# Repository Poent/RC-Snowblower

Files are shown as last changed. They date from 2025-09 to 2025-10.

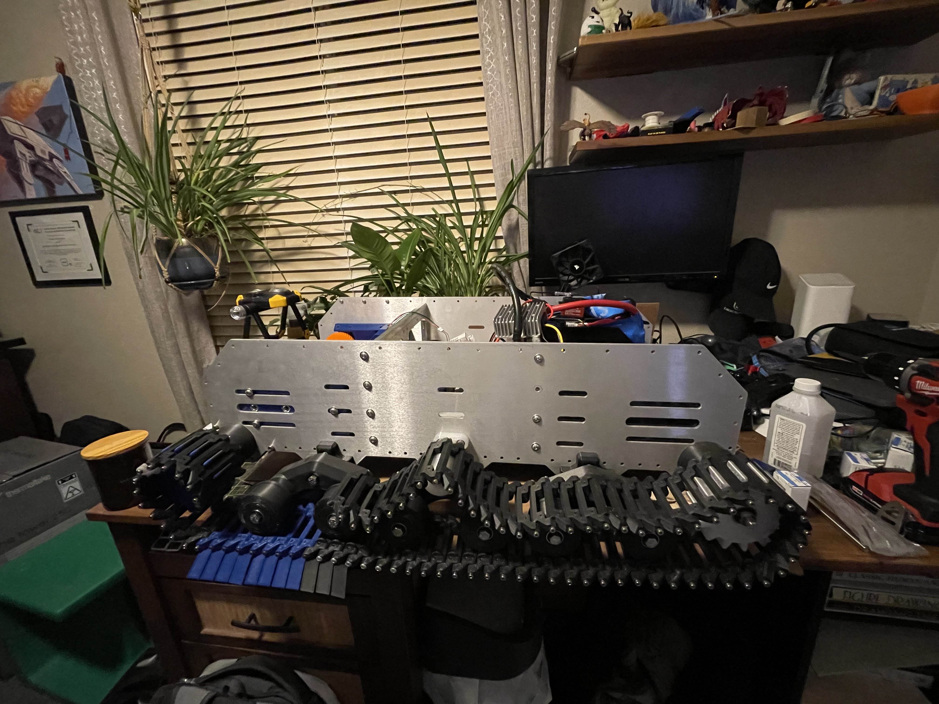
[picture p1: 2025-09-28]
Images/Sep 2025 Progress.jpg

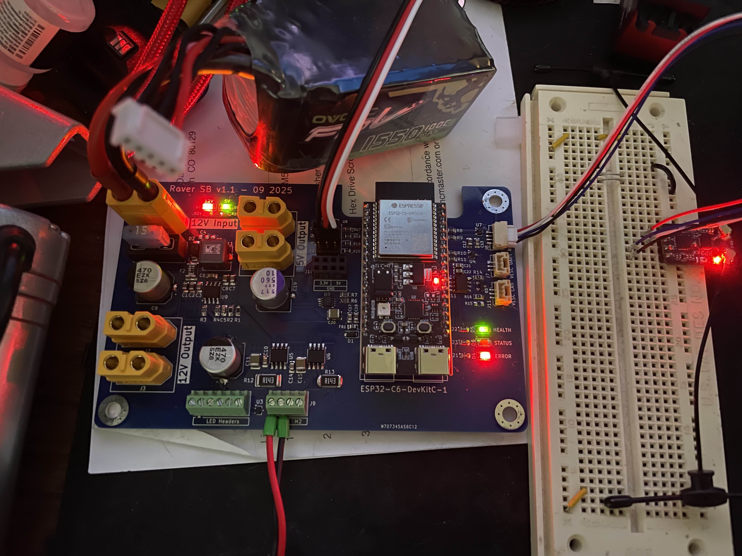
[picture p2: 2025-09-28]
Images/PCB-First-Boot.jpg

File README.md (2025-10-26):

# RC Snowblower Project

2025-09-27_19h33_31

====
LATEST UPDATES (10-26-2025):

2025-10-26_12h57_35

Working on designing the impeller and auger portion of the snowblower. Switched from using a worm gear assembly to a custom ring and pinion setup using a spiral bevel gear. Motor is a 190KV motor being driven at 38v nominal. Motor at full power (which we'll never do) will spin at about 7,200 RPM. the motor goes through a 3:1 reduction to the impeller. Impeller will spin at <2400 RPM. The impeller drives the input shaft of the auger gearbox, which has a 9:1 reduction. At full power that will result in the auger at about 250rpm. All of these are design maximums. The motor will likely be RPM limited to 60% total power in the VESC, more than halving all these totals. 

Hello everyone! Welcome to my crazy project.

Before diving into the details, here’s quick background on me and why I’m building this. Feel free to skip down to the status if you want the meat.

=====

### Who I am
I’m a tech leader in the OT/MSP space with ~15 years in IT services. I own our MSP tool stack, cybersecurity program, and AI/automation initiatives. I’m CISSP-certified and studied electrical engineering, game development/design, and aviation management in college. I have a wonderful wife and two kids, and my hobbies include art, design, programming, 3D printing, woodworking, and more.

### How this project started
About two years ago my wife sent me a video of the Yarbo snowblower. It’s a tracked outdoor platform with attachments for mowing, snowblowing, hauling, etc., and it can go fully autonomous with an RTK/GNSS setup. I loved it… until I saw it was about $5,000, which I can’t justify for a <15-foot driveway.

Then she sent a smiliar (but different) 3D-printed snowblower video. Once again I was hyped to look at building it, but the "basic" kit alone was about $4,000. My dreams were dashed again—but the seed was planted.... I’ve got experience with CAD, 3D printing, and electronics, so I decided to try building my own!

That’s this project. While my BOM is under $4k... it is far more expensive than I initially anticipated and I have a far higher respect for those alternatives. 

### What to expect here
I can't honestly recommend anyone replicate this build. Better platforms exist, and I'm not an engineer! While I intend to make everything functional, resilient, and high quality... there WILL be problems. If you choose to follow along or, god forbid, try to build one of these yourself.... PLEASE understand what you're getting into. It WILL be a significant investment and there is NO garuntee of a working platform at the end of it. Please don't anticipate assistance of any kind if you choose to build this. BUT.... if you do... please tell me! I would love to see what other people do. I intend to make and keep this project fully open source, and I have no dreams of making this into a commercial product at any point in time. 

For those of you that want to just check it out and/or follow along - then sit back, and enjoy the ride!

## Status

**Completed**
- Chassis assembled with CNC aluminum frame and 3D-printed interconnects
- Power system using Headway 40152 LiFePO₄ cells and JK BMS
- V1 controller board designed, produced, soldered, and tested
- Basic ESP32 firmware with CRSF input and VESC CAN telemetry
- Initial drivetrain movement tests

**In Progress**
- Finalizing V1 firmware for the ESP32 and carrier board
- Universal mount for the snowblower attachment
- Track stress testing and refinement
- Chassis cover design and integration (sealed against snow)

**Planned**
- Blower attachment design and integration
- Public-ready docs for CAD, electronics, and firmware
- BOM refinement for cost and reliability

# LATEST IMAGES
2025-09-27_19h33_31


Sep 2025 Progress 02
Sep 2025 Progress

2025-09-27_19h49_34
2025-09-27_19h50_09
2025-09-27_19h51_03

PCB-blanks

PCB-First-Boot

# Progress

**Completed:**
- Chassis structure assembled with CNC aluminum frame and 3D-printed interconnects  
- Power system finalized around Headway LiFePO₄ cells and JK BMS (150A).
- Custom V1 of controller board - Designed, produced, soldered, and tested.
- Basic firmware running on ESP32 with input decoding and VESC telemetry working. 
- Initial testing of drivetrain and basic movement functions

**In Progress:**
- Finalize V1 Firmware for ESP32 and carrier board
- Design and implement universal mount for snowblower attachment. 
- Track stress testing and refinement
- Chassis cover design and integration (sealed against snow ingress) - NOT STARTED

**Future work:**
- Design blower attachment and integration.
- Preparing the project for public release (this repository) and planning documentation for CAD, electronics, and firmware.
- Refine parts list and BOM to reduce cost, complexity, and improve reliability.

## Overview
This repository will contain (wish list) the complete design and implementation files for a remote-controlled snowblower, including:

- **CAD Models**: 3D designs and mechanical components
- **Electronics**: Circuit designs, PCB layouts, and component specifications
- **Code**: Control software and firmware
- **Documentation**: Build guides, specifications, and user manuals
- **Images**: Photos, diagrams, and visual documentation
- **Build Log**: Chronological record of design iterations, testing, and modifications

## Repository Structure

```
├── CAD/           # 3D models, drawings, and mechanical designs
├── Code/          # Control software and firmware
├── Docs/          # Documentation and guides
├── Electronics/   # Circuit designs and electrical components
├── Images/        # Photos, diagrams, and visual documentation
└── Build_Log/    # Chronological record of design iterations and testing

```

## Features (Planned)
- [done] Remote control operation
- [done] Variable speed control
- [done] High-performance BLDC motors with custom gearboxes
- [ ] Weather-resistant design
- [ ] Modular component system
- [ ] Universal Mount for attachments (snowblower, plow, etc.)

### Wish List
- Autonomous navigation capabilities
- Real-time telemetry
- Produce fully open-source hardware and software
- Develop 3D printed versions of key components to reduce cost

## Hardware Requirements
*To be documented*

## Software Requirements
*To be documented*

## Getting Started
*Build instructions coming soon*

## Contributing
*Contribution guidelines to be added*

## License
*License information to be added*

## Contact
*Contact information to be added*

---
*This README will be updated as the project progresses.*

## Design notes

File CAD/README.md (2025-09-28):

# CAD Files
This directory will contain all CAD files related to the RC Snowblower project. Placeholder for now...

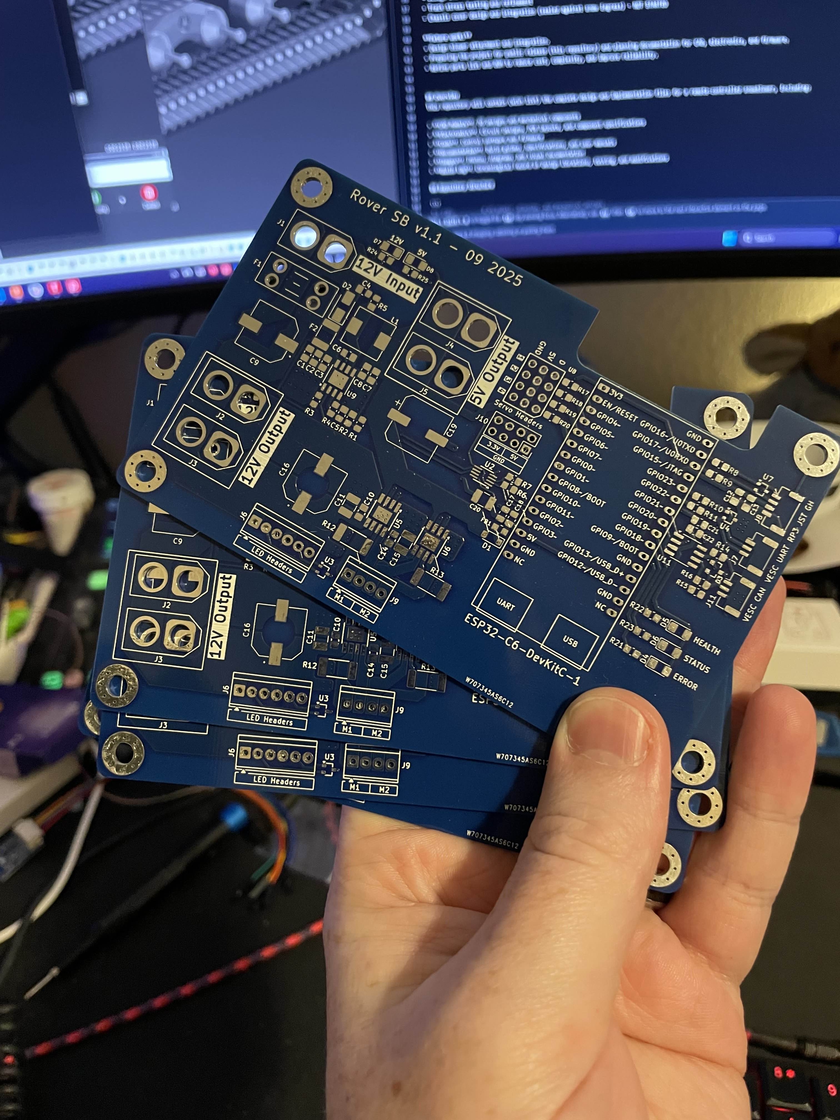
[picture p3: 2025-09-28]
Images/PCB-blanks.jpg

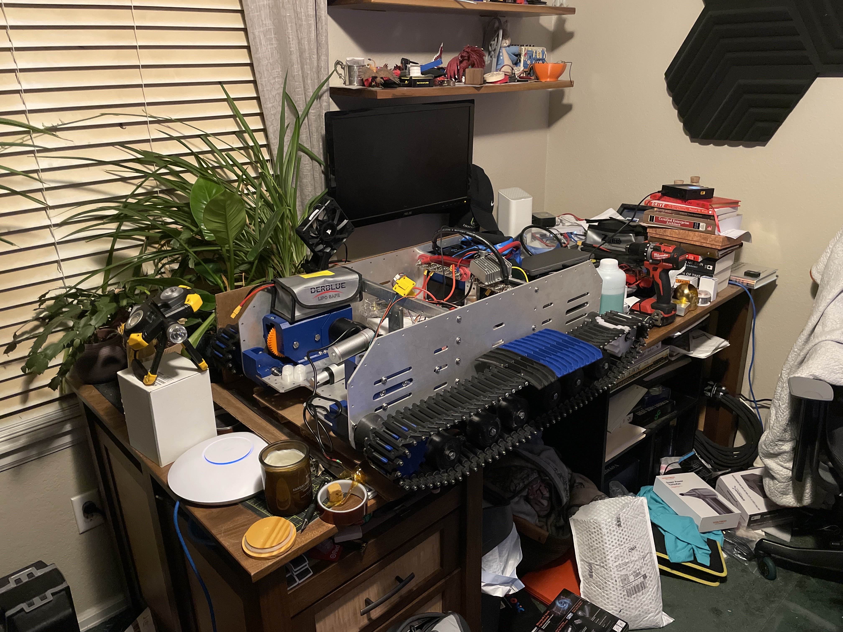
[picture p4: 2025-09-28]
Images/Sep 2025 Progress 02.jpg

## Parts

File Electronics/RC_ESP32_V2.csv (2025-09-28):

Reference | Qty | Value | DNP | Exclude from BOM | Exclude from Board | Footprint | Footprint_Short | MFG Part # | Datasheet | Description
C1,C2,C12,C18 | 4 | 10uF |  |  |  | Capacitor_SMD:C_0805_2012Metric_Pad1.18x1.45mm_HandSolder | 0805 | GRM21BZ71E106KE15L | https://www.digikey.com/en/products/detail/murata-electronics/GRM21BZ71E106KE15L/13904911 | Confirmed - 50
C3,C6,C10,C13,C14,C17,C21 | 7 | 0.1uF |  |  |  | Capacitor_SMD:C_0805_2012Metric_Pad1.18x1.45mm_HandSolder | 0805 | KGM21NR71E104KT | https://www.digikey.com/en/products/detail/kyocera-avx/KGM21NR71E104KT/1116281 | Confirmed - 50
C5 | 1 | 0.47uF |  |  |  | Capacitor_SMD:C_0805_2012Metric_Pad1.18x1.45mm_HandSolder | 0805 | GRM188R71E474KA12D | https://www.digikey.com/en/products/detail/murata-electronics/GRM188R71E474KA12D/702555 | Confirmed - 10
C7,C8 | 2 | 22uF |  |  |  | Capacitor_SMD:C_0805_2012Metric_Pad1.18x1.45mm_HandSolder | 0805 | GRM21BR61C226ME44L | https://www.digikey.com/en/products/detail/murata-electronics/GRM21BR61C226ME44L/4905531 | Confirmed - 25
C9,C16 | 2 | 470uF |  |  |  | Libraries:CAP_EEHZU1E471P | Radial, Can - SMD 10mm | EEH-ZU1E471P | https://www.digikey.com/en/products/detail/panasonic-electronic-components/EEH-ZU1E471P/14114075 | Confirmed - 10
C11,C15,C20 | 3 | 47uF |  |  |  | Capacitor_SMD:C_1210_3225Metric_Pad1.33x2.70mm_HandSolder | 1210 | TMK325ABJ476MM-P | https://www.digikey.com/en/products/detail/taiyo-yuden/TMK325ABJ476MM-P/7067064 | Confirmed - 20
C19 | 1 | 560uF |  |  |  | Capacitor_SMD:CP_Elec_10x7.9 | Radial, Can - SMD 10mm | 10SVP560M | https://www.digikey.com/en/products/detail/panasonic-electronic-components/10SVP560M/4204770 | Confirmed - 10
C22 | 1 | 1uF |  |  |  | Capacitor_SMD:C_0805_2012Metric_Pad1.18x1.45mm_HandSolder | 0805 | GRM21BR71A105KA01K | https://www.digikey.com/en/products/detail/murata-electronics/GRM21BR71A105KA01K/2546935 | Confirmed - 20
D1 | 1 | sch |  |  |  | Diode_SMD:D_SOD-123 | SOD-123 | B5819W | https://www.digikey.com/en/products/detail/good-ark-semiconductor/B5819W/18648698 | Confirmed - 10
D2 | 1 | SMAJ15A |  |  |  | Diode_SMD:D_SMA | DO-214AC, SMA | SMAJ15A | https://www.digikey.com/en/products/detail/bourns-inc/SMAJ15A/2254246 | Confirmed - 10
D3 | 1 | SM24CANB-02HTG |  |  |  | Libraries:SM24CANB02HTG | SOT-23-3 | SM24CANB-02HTG | https://www.digikey.com/en/products/detail/littelfuse-inc/SM24CANB-02HTG/5048174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 | Confirmed - 10
D4,D7 | 2 | RED |  |  |  | LED_SMD:LED_1206_3216Metric_Pad1.42x1.75mm_HandSolder | 1206 | QTLP650D2TR | https://www.digikey.com/en/products/detail/everlight-electronics-co-ltd/QTLP650D2TR/2675908 | Confirmed - 10
D5,D8 | 2 | GRN |  |  |  | LED_SMD:LED_1206_3216Metric_Pad1.42x1.75mm_HandSolder | 1206 | QTLP650D4TR/QT15-21SYGD/S530-E2/TR8 | https://www.digikey.com/en/products/detail/everlight-electronics-co-ltd/QTLP650D4TR-QT15-21SYGD-S530-E2-TR8/2675910 | Confirmed - 10
D6 | 1 | BLU |  |  |  | LED_SMD:LED_1206_3216Metric_Pad1.42x1.75mm_HandSolder | 1206 | HSMR-C150 | https://www.digikey.com/en/products/detail/broadcom-limited/HSMR-C150/637697 | Confirmed - 10
F1 | 1 | 15A |  |  |  | Fuse:Fuseholder_Blade_Mini_Keystone_3568 | 36-3568-ND | 36-3568-ND | https://www.digikey.com/en/products/detail/keystone-electronics/3568/2137306 | Confirmed - 5
F2 | 1 | 1812L260/16MR |  |  |  | Fuse:Fuse_1812_4532Metric_Pad1.30x3.40mm_HandSolder | 1812 | 1812L260/16MR | https://www.digikey.com/en/products/detail/littelfuse-inc/1812L260-16MR/4556471 | Confirmed - 10
FB1 | 1 | FerriteBead_Small |  |  |  | digikey-footprints:0805 | 0805 | BLM21PG121SN1D | https://www.digikey.com/en/products/detail/murata-electronics/BLM21PG121SN1D/2588110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 | Confirmed - 10
J6 | 1 | LED Headers |  |  |  | TerminalBlock_TE-Connectivity:TerminalBlock_TE_282834-6_1x06_P2.54mm_Horizontal | 1x06 2.45mm pitch | OSTVN06A150 | https://www.digikey.com/en/products/detail/on-shore-technology-inc/OSTVN06A150/1588866 | Confirmed - 10
J7 | 1 | VESC UART |  |  |  | Connector_JST:JST_GH_BM03B-GHS-TBT_1x03-1MP_P1.25mm_Vertical |  | BM03B-GHS-TBT | https://www.digikey.com/en/products/detail/jst-sales-america-inc/BM03B-GHS-TBT/807801 | Confirmed - 5
J8 | 1 | RP3 JST GH |  |  |  | Connector_JST:JST_GH_BM04B-GHS-TBT_1x04-1MP_P1.25mm_Vertical |  | SM04B-GHS-TB | https://www.digikey.com/en/products/detail/jst-sales-america-inc/SM04B-GHS-TB/807788 | Confirmed - 6
J9 | 1 | Motor Block |  |  |  | TerminalBlock_TE-Connectivity:TerminalBlock_TE_282834-4_1x04_P2.54mm_Horizontal | 1x04 2.45mm pitch | OSTVN04A150 | https://www.digikey.com/en/products/detail/on-shore-technology-inc/OSTVN04A150/1588864 | Confirmed - 10
J10 | 1 | Power Header |  |  |  | Connector_PinSocket_2.54mm:PinSocket_2x04_P2.54mm_Vertical | 2x04 2.45mm pitch | PPTC042LFBN-RC | https://www.digikey.com/en/products/detail/sullins-connector-solutions/PPTC042LFBN-RC/810211 | Confirmed - 10
J11 | 1 | VESC CAN |  |  |  | Connector_JST:JST_GH_BM03B-GHS-TBT_1x03-1MP_P1.25mm_Vertical |  | BM03B-GHS-TBT | https://www.digikey.com/en/products/detail/jst-sales-america-inc/BM03B-GHS-TBT/807801 | Confirmed - 5
L1 | 1 | 3.3uH |  |  |  | Libraries:L_Wurth_WE-HCC-8070 | Nonstandard | 7443340330 | https://www.digikey.com/en/products/detail/w%C3%BCrth-elektronik/7443340330/2175581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 | Confirmed - 6
R1 | 1 | 365k |  |  |  | Resistor_SMD:R_0805_2012Metric_Pad1.20x1.40mm_HandSolder | 0805 | ERA-6AEB3653V | https://www.digikey.com/en/products/detail/panasonic-electronic-components/ERA-6AEB3653V/2025893 | Confirmed - 10
R2 | 1 | 49.9k |  |  |  | Resistor_SMD:R_0805_2012Metric_Pad1.20x1.40mm_HandSolder | 0805 | ERA-6AEB4992V | https://www.digikey.com/en/products/detail/panasonic-electronic-components/ERA-6AEB4992V/2025816 | Confirmed - 10
R3 | 1 | 10k |  |  |  | Resistor_SMD:R_0805_2012Metric_Pad1.20x1.40mm_HandSolder | 0805 | ERA-6AEB103V | https://www.digikey.com/en/products/detail/panasonic-electronic-components/ERA-6AEB103V/1465773 | Confirmed - 10
R4,R6,R7 | 3 | 100k |  |  |  | Resistor_SMD:R_0805_2012Metric_Pad1.20x1.40mm_HandSolder | 0805 | ERA-6AEB104V | https://www.digikey.com/en/products/detail/panasonic-electronic-components/ERA-6AEB104V/1465797 | Confirmed - 25
R8,R9,R10,R11,R17,R18,R19,R20 | 8 | 47 |  |  |  | Resistor_SMD:R_0805_2012Metric_Pad1.20x1.40mm_HandSolder | 0805 | CRGCQ0805F47R | https://www.digikey.com/en/products/detail/te-connectivity-passive-product/CRGCQ0805F47R/8576335 | Confirmed - 50
R12,R13 | 2 | 0.143 |  |  |  | Resistor_SMD:R_2512_6332Metric_Pad1.40x3.35mm_HandSolder | 2512 | RLC73PW3AR143FTDG | https://www.digikey.com/en/products/detail/te-connectivity-passive-product/RLC73PW3AR143FTDG/19237034 | Confirmed 12
R14,R16 | 2 | 0 |  |  |  | Resistor_SMD:R_0805_2012Metric_Pad1.20x1.40mm_HandSolder | 0805 | CR0805-J/-000ELF | https://www.digikey.com/en/products/detail/bourns-inc/CR0805-J-000ELF/3593157 | Confirmed - 25
R21,R22 | 2 | 620 |  |  |  | Resistor_SMD:R_0805_2012Metric_Pad1.20x1.40mm_HandSolder | 0805 | RC0805FR-07620RL | https://www.digikey.com/en/products/detail/yageo/RC0805DR-07100RL/22200903 | Confirmed - 25
R23 | 1 | 330 |  |  |  | Resistor_SMD:R_0805_2012Metric_Pad1.20x1.40mm_HandSolder | 0805 | AC0805FR-07330RL | https://www.digikey.com/en/products/detail/yageo/AC0805FR-07330RL/5896770 | Confirmed - 25
R24 | 1 | 4700 |  |  |  | Resistor_SMD:R_0805_2012Metric_Pad1.20x1.40mm_HandSolder | 0805 | AC0805FR-074K7L | https://www.digikey.com/en/products/detail/yageo/AC0805FR-074K7L/5896876 | Confirmed - 25
R25 | 1 | 1500 |  |  |  | Resistor_SMD:R_0805_2012Metric_Pad1.20x1.40mm_HandSolder | 0805 | RC0805JR-071K5L | https://www.digikey.com/en/products/detail/yageo/RC0805JR-071K5L/728230 | Confirmed - 25
U2 | 1 | SN74LVC2T45 |  |  |  | Package_SO:SSOP-8_2.95x2.8mm_P0.65mm | 8-VFSOP | SN74LVC2T45DCUR | https://www.digikey.com/en/products/detail/texas-instruments/SN74LVC2T45DCUR/657833 | (Logic Level Shifter) Dual-Bit Dual-Supply Bus Transceiver With Configurable Voltage Translation and 3-State Outputs, VSSOP-8
U3,U4,U7 | 3 | TPD2E2U06DCK |  |  |  | Package_TO_SOT_SMD:SOT-323_SC-70 | SC-70, SOT-323 | TPD2E2U06DCKR | http://www.ti.com/lit/ds/symlink/tpd2e2u06.pdf | Dual-Channel High-Speed ESD Protection, SC-70
U5,U6 | 2 | DRV8251 |  |  |  | Package_SO:TI_SO-PowerPAD-8 | 8-PowerSOIC | DRV8251DDAR | https://www.digikey.com/en/products/detail/texas-instruments/DRV8251DDAR/15857248 | (Motor Driver) DRV8251DDAR
U8 | 1 | Servo Headers |  |  |  | Custom_Parts:03x04 Generic Pin Header | 3x12 2.54mm | TSW-104-07-L-T | https://www.digikey.com/en/products/detail/samtec-inc/TSW-104-07-L-T/6692021 | Confirmed - 5
U9 | 1 | TPS56528DDA |  |  |  | Package_SO:Texas_HSOP-8-1EP_3.9x4.9mm_P1.27mm_ThermalVias | 8-PowerSOIC | TPS56528DDAR | https://www.digikey.com/en/products/detail/texas-instruments/TPS56528DDAR/4037191 | 5A Synchronous Step-Down Voltage Regulator, Adjustable Output Voltage 0.6-7V, 4.5-18V Input Voltage, SO-8EP
U11 | 1 | TCAN332GDR |  |  |  | Package_SO:SOIC-8_3.9x4.9mm_P1.27mm | SOIC8 3.9mm | TCAN332GDR | https://www.digikey.com/en/products/detail/texas-instruments/TCAN332GDR/6572321 | High-Speed CAN Transceiver with CAN FD, 5Mbps, 3.3V supply, SOT-23-8/SOIC-8

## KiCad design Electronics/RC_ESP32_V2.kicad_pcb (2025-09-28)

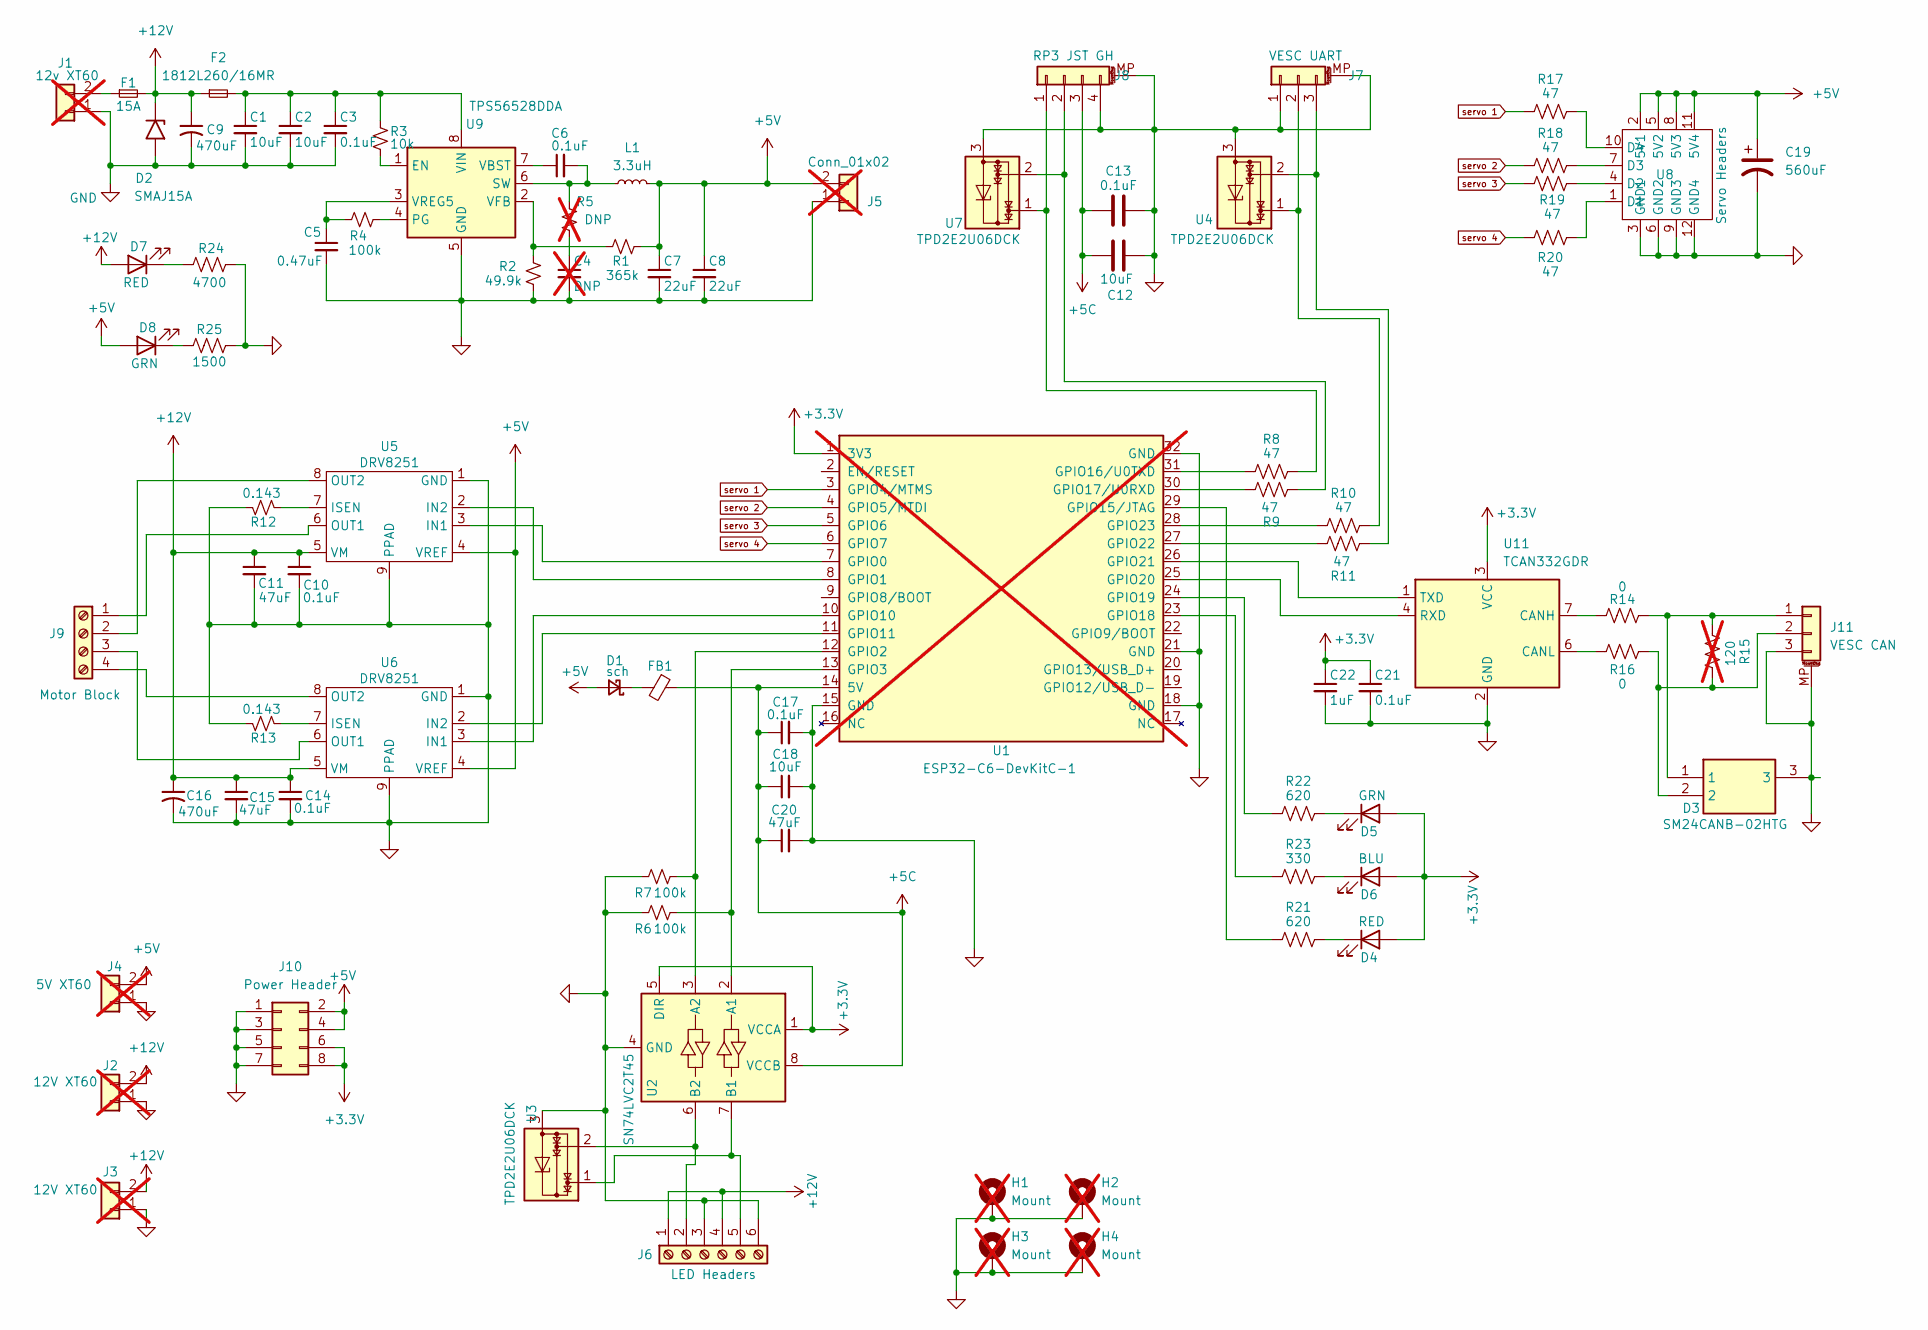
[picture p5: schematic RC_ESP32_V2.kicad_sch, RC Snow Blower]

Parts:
C1, C2, C12, C18: 10uF; C_0805_2012Metric_Pad1.18x1.45mm_HandSolder; MFG Part # GRM21BZ71E106KE15L
C3, C6, C10, C13, C14, C17, C21: 0.1uF; C_0805_2012Metric_Pad1.18x1.45mm_HandSolder; MFG Part # KGM21NR71E104KT
C4: DNP; C_0805_2012Metric_Pad1.18x1.45mm_HandSolder; not fitted
C5: 0.47uF; C_0805_2012Metric_Pad1.18x1.45mm_HandSolder; MFG Part # GRM188R71E474KA12D
C7, C8: 22uF; C_0805_2012Metric_Pad1.18x1.45mm_HandSolder; MFG Part # GRM21BR61C226ME44L
C9, C16: 470uF; CAP_EEHZU1E471P; MFG Part # EEH-ZU1E471P
C11, C15, C20: 47uF; C_1210_3225Metric_Pad1.33x2.70mm_HandSolder; MFG Part # TMK325ABJ476MM-P
C19: 560uF; CP_Elec_10x7.9; MFG Part # 10SVP560M
C22: 1uF; C_0805_2012Metric_Pad1.18x1.45mm_HandSolder; MFG Part # GRM21BR71A105KA01K
D1: sch; D_SOD-123; MFG Part # B5819W
D2: SMAJ15A; D_SMA; MFG Part # SMAJ15A
D3: SM24CANB-02HTG; SM24CANB02HTG; Manufacturer_Part_Number SM24CANB-02HTG; Mouser Part Number 576-SM24CANB-02HTG
D4, D7: RED; LED_1206_3216Metric_Pad1.42x1.75mm_HandSolder; MFG Part # QTLP650D2TR
D5, D8: GRN; LED_1206_3216Metric_Pad1.42x1.75mm_HandSolder; MFG Part # QTLP650D4TR/QT15-21SYGD/S530-E2/TR8
D6: BLU; LED_1206_3216Metric_Pad1.42x1.75mm_HandSolder; MFG Part # HSMR-C150
F1: 15A; Fuseholder_Blade_Mini_Keystone_3568; MFG Part # 36-3568-ND
F2: 1812L260/16MR; Fuse_1812_4532Metric_Pad1.30x3.40mm_HandSolder; MFG Part # 1812L260/16MR
FB1: FerriteBead_Small; 0805; MFG Part # BLM21PG121SN1D
H1, H2, H3, H4: Mount; MountingHole_4.3mm_M4_Pad_Via; not fitted
J1: 12v XT60; AMASS_XT60-M_1x02_P7.20mm_Vertical; MFG Part # XT60-M; not fitted
J2, J3: 12V XT60; AMASS_XT60-F_1x02_P7.20mm_Vertical; MFG Part # XT60-F; not fitted
J4: 5V XT60; AMASS_XT60-F_1x02_P7.20mm_Vertical; MFG Part # XT60-F; not fitted
J5: Conn_01x02; AMASS_XT60-F_1x02_P7.20mm_Vertical; MFG Part # XT60-F; not fitted
J6: LED Headers; TerminalBlock_TE_282834-6_1x06_P2.54mm_Horizontal; MFG Part # OSTVN06A150
J7: VESC UART; JST_GH_BM03B-GHS-TBT_1x03-1MP_P1.25mm_Vertical; MFG Part # BM03B-GHS-TBT
J8: RP3 JST GH; JST_GH_BM04B-GHS-TBT_1x04-1MP_P1.25mm_Vertical; MFG Part # SM04B-GHS-TB
J9: Motor Block; TerminalBlock_TE_282834-4_1x04_P2.54mm_Horizontal; MFG Part # OSTVN04A150
J10: Power Header; PinSocket_2x04_P2.54mm_Vertical; MFG Part # PPTC042LFBN-RC
J11: VESC CAN; JST_GH_BM03B-GHS-TBT_1x03-1MP_P1.25mm_Vertical; MFG Part # BM03B-GHS-TBT
L1: 3.3uH; L_Wurth_WE-HCC-8070; MFG Part # 7443340330
R1: 365k; R_0805_2012Metric_Pad1.20x1.40mm_HandSolder; MFG Part # ERA-6AEB3653V
R2: 49.9k; R_0805_2012Metric_Pad1.20x1.40mm_HandSolder; MFG Part # ERA-6AEB4992V
R3: 10k; R_0805_2012Metric_Pad1.20x1.40mm_HandSolder; MFG Part # ERA-6AEB103V
R4, R6, R7: 100k; R_0805_2012Metric_Pad1.20x1.40mm_HandSolder; MFG Part # ERA-6AEB104V
R5: DNP; R_0805_2012Metric_Pad1.20x1.40mm_HandSolder; not fitted
R8, R9, R10, R11, R17, R18, R19, R20: 47; R_0805_2012Metric_Pad1.20x1.40mm_HandSolder; MFG Part # CRGCQ0805F47R
R12, R13: 0.143; R_2512_6332Metric_Pad1.40x3.35mm_HandSolder; MFG Part # RLC73PW3AR143FTDG
R14, R16: 0; R_0805_2012Metric_Pad1.20x1.40mm_HandSolder; MFG Part # CR0805-J/-000ELF
R15: 120; R_0805_2012Metric_Pad1.20x1.40mm_HandSolder; MFG Part # ERA-6AEB101V; not fitted
R21, R22: 620; R_0805_2012Metric_Pad1.20x1.40mm_HandSolder; MFG Part # RC0805FR-07620RL
R23: 330; R_0805_2012Metric_Pad1.20x1.40mm_HandSolder; MFG Part # AC0805FR-07330RL
R24: 4700; R_0805_2012Metric_Pad1.20x1.40mm_HandSolder; MFG Part # AC0805FR-074K7L
R25: 1500; R_0805_2012Metric_Pad1.20x1.40mm_HandSolder; MFG Part # RC0805JR-071K5L
U1: ESP32-C6-DevKitC-1; not fitted
U2: SN74LVC2T45; SSOP-8_2.95x2.8mm_P0.65mm; MFG Part # SN74LVC2T45DCUR
U3, U4, U7: TPD2E2U06DCK; SOT-323_SC-70; MFG Part # TPD2E2U06DCKR
U5, U6: DRV8251; TI_SO-PowerPAD-8; MFG Part # DRV8251DDAR
U8: Servo Headers; 03x04 Generic Pin Header; MFG Part # TSW-104-07-L-T
U9: TPS56528DDA; Texas_HSOP-8-1EP_3.9x4.9mm_P1.27mm_ThermalVias; MFG Part # TPS56528DDAR
U11: TCAN332GDR; SOIC-8_3.9x4.9mm_P1.27mm; MFG Part # TCAN332GDR

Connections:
+3.3V: C21.1, C22.1, D4.2 (A), D5.2 (A), D6.2 (A), J10.6, J10.8, U1.1 (3V3), U2.1 (VCCA), U2.5 (DIR), U11.3 (VCC)
+5C: C12.1, C13.1, C17.1, C18.1, C20.1, FB1.1, J8.3, U1.14 (5V), U2.8 (VCCB)
+5V: C7.1, C8.1, C19.1, D1.2 (A), D8.2 (A), J4.2, J5.2, J10.2, J10.4, L1.2, R1.1, U5.4 (VREF), U6.4 (VREF), U8.2 (5V1), U8.5 (5V2), U8.8 (5V3), U8.11 (5V4)
+12V: C9.1, C10.1, C11.1, C14.1, C15.1, C16.1, D2.1 (A1), D7.2 (A), F1.2, F2.1, J2.2, J3.2, J6.1, J6.4, U5.5 (VM), U6.5 (VM)
GND: C1.2, C2.2, C3.2, C4.2, C5.2, C7.2, C8.2, C9.2, C10.2, C11.2, C12.2, C13.2, C14.2, C15.2, C16.2, C17.2, C18.2, C19.2, C20.2, C21.2, C22.2, D2.2 (A2), D3.3, H1.1, H2.1, H3.1, H4.1, J1.1, J2.1, J3.1, J4.1, J5.1, J6.3, J6.6, J7.1, J7.MP (MountPin), J8.4, J8.MP (MountPin), J10.1, J10.3, J10.5, J10.7, J11.3, J11.MP (MountPin), R2.1, R6.1, R7.1, R12.2, R13.2, R24.1, R25.2, U1.15 (GND), U1.18 (GND), U1.21 (GND), U1.32 (GND), U2.4 (GND), U3.3, U4.3, U5.1 (GND), U5.9 (PPAD), U6.1 (GND), U6.9 (PPAD), U7.3, U8.3 (GND1), U8.6 (GND2), U8.9 (GND3), U8.12 (GND4), U9.5 (GND), U9.9 (GND), U11.2 (GND)
unnamed: C4.1, R5.2
unnamed: D1.1 (K), FB1.2
unnamed: D4.1 (K), R21.2
unnamed: D5.1 (K), R22.2
unnamed: D6.1 (K), R23.2
unnamed: D7.1 (K), R24.2
unnamed: D8.1 (K), R25.1
unnamed: F1.1, J1.2
unnamed: J6.2, U2.6 (B2), U3.2
unnamed: J6.5, U2.7 (B1), U3.1
unnamed: J7.2, R10.2, U4.1
unnamed: J7.3, R11.2, U4.2
unnamed: J8.1, R8.2, U7.1
unnamed: J8.2, R9.2, U7.2
unnamed: J9.1, U5.6 (OUT1)
unnamed: J9.2, U5.8 (OUT2)
unnamed: J9.3, U6.6 (OUT1)
unnamed: J9.4, U6.8 (OUT2)
unnamed: D3.1, J11.1, R14.1, R15.2
unnamed: D3.2, J11.2, R15.1, R16.1
unnamed: U1.7 (GPIO0), U5.3 (IN1)
unnamed: U1.8 (GPIO1), U5.2 (IN2)
unnamed: R7.2, U1.12 (GPIO2), U2.3 (A2)
unnamed: R6.2, U1.13 (GPIO3), U2.2 (A1)
unnamed: U1.10 (GPIO10), U6.3 (IN1)
unnamed: U1.11 (GPIO11), U6.2 (IN2)
unnamed: R21.1, U1.29 (GPIO15/JTAG)
unnamed: R8.1, U1.31 (GPIO16/U0TXD)
unnamed: R9.1, U1.30 (GPIO17/U0RXD)
unnamed: R23.1, U1.23 (GPIO18)
unnamed: R22.1, U1.24 (GPIO19)
unnamed: U1.25 (GPIO20), U11.4 (RXD)
unnamed: U1.26 (GPIO21), U11.1 (TXD)
unnamed: R11.1, U1.27 (GPIO22)
unnamed: R10.1, U1.28 (GPIO23)
unnamed: R12.1, U5.7 (ISEN)
unnamed: R13.1, U6.7 (ISEN)
unnamed: R20.2, U8.1 (D1)
unnamed: R19.2, U8.4 (D2)
unnamed: R18.2, U8.7 (D3)
unnamed: R17.2, U8.10 (D4)
unnamed: R3.2, U9.1 (EN)
unnamed: R4.1, U9.4 (PG)
unnamed: C6.2, L1.1, R5.1, U9.6 (SW)
unnamed: C6.1, U9.7 (VBST)
unnamed: R1.2, R2.2, U9.2 (VFB)
unnamed: C1.1, C2.1, C3.1, F2.2, R3.1, U9.8 (VIN)
unnamed: C5.1, R4.2, U9.3 (VREG5)
unnamed: R14.2, U11.7 (CANH)
unnamed: R16.2, U11.6 (CANL)
servo 1: R17.1, U1.3 (GPIO4/MTMS)
servo 2: R18.1, U1.4 (GPIO5/MTDI)
servo 3: R19.1, U1.5 (GPIO6)
servo 4: R20.1, U1.6 (GPIO7)

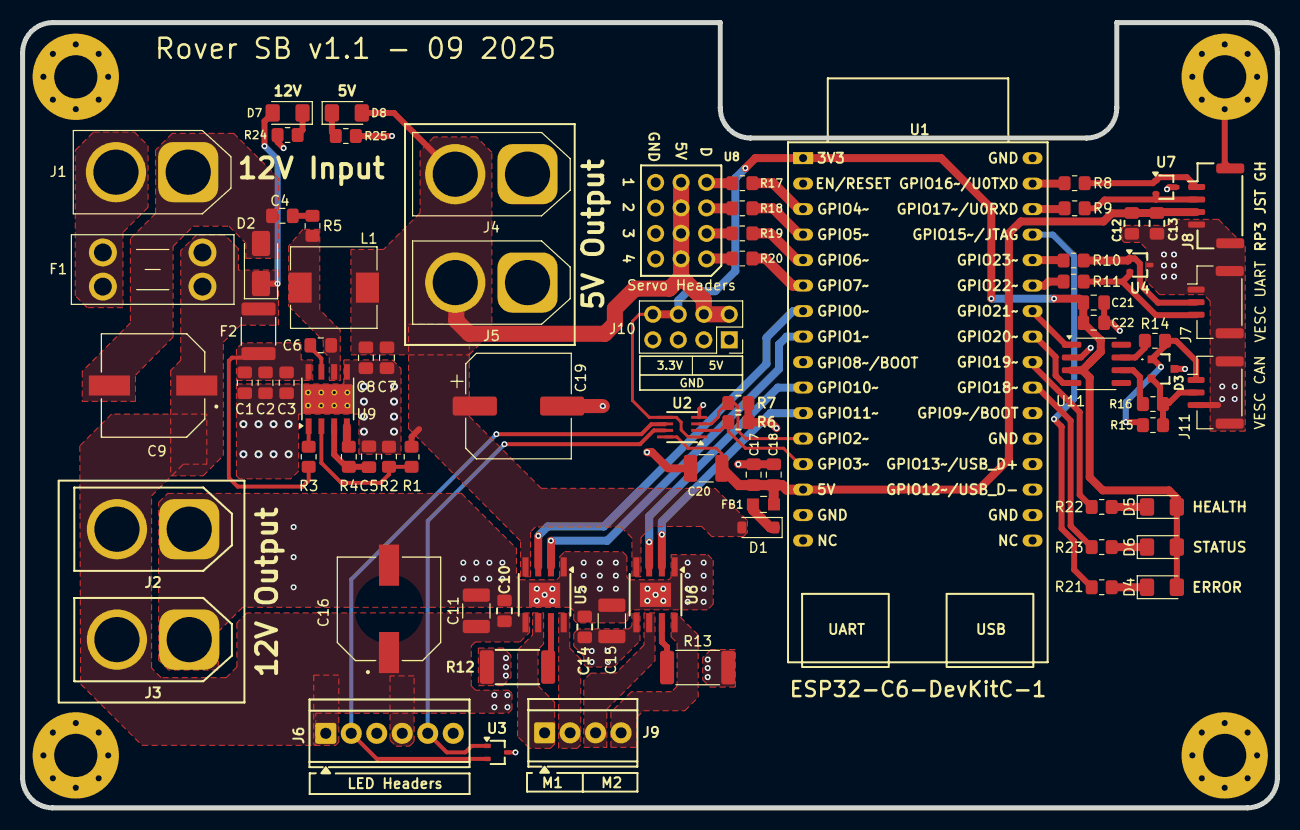
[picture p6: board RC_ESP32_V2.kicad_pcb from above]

Board: 2 copper layers, 125.0 x 78.2 mm, 84 parts (0 on the bottom side), 59 nets.
